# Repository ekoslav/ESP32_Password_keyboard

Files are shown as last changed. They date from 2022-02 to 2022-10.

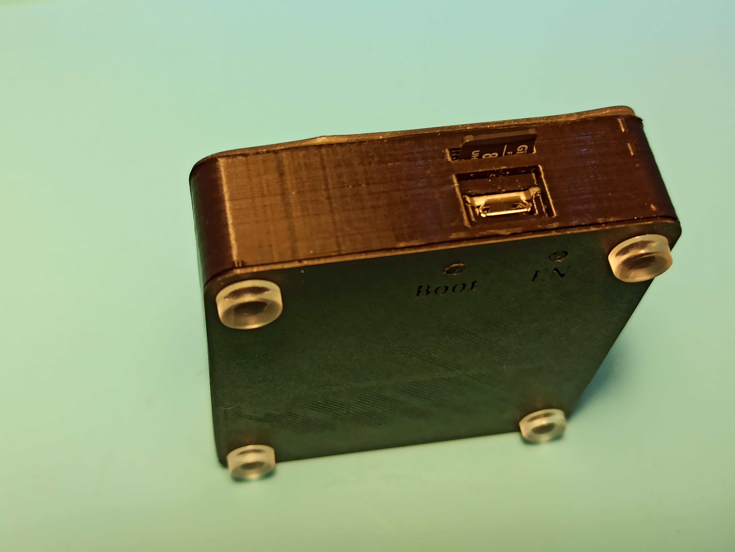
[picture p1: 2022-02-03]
Images/BACK_assembled.jpg

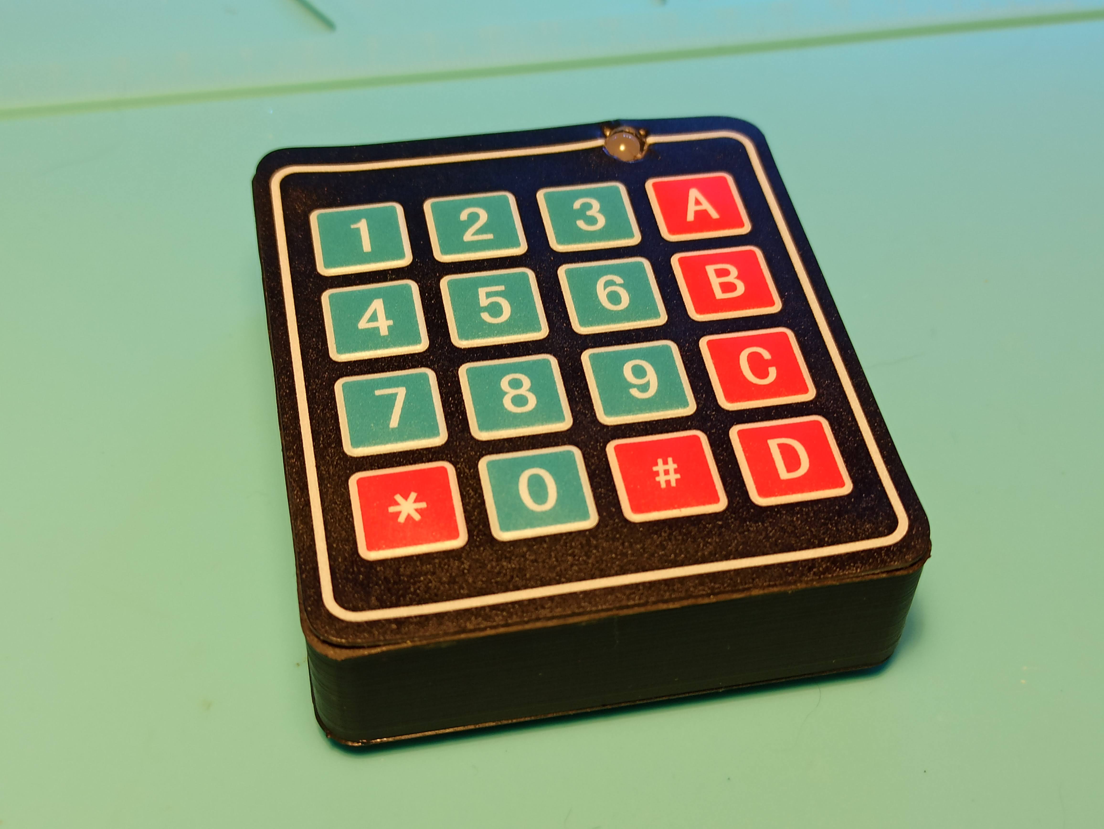
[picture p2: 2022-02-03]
Images/TOP_assembled.jpg

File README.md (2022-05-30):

# ESP32_Password_keyboard
Bluetooth password keyboard using the ESP32

Versions:

1.0 February 1st, 2022 - First public version

Description:

This project uses a ESP32, 4x4 matrix keyboard, an SD card reader, and a RGB LED.
The goal is to create a macro / password keyboard with 8 banks of 15 key mappings.

The star (*) key is used for shifting trought the key assignemnt banks.

Each bank has a corresponding file on the SD card.
The file should have 15 lines with macro sequences, and at least one blank line at the end.
The first line corresponds to the key "1", then 2 trough D, and the last is sequence for the key "#".

------------------------------------------------------------------------------------------------------
Examples for macro sequences:

1) just a plain text:

somekeycombination

2) text with tab key at the end:

username\t

3) text with enter key at the end:

password\n

or

password\r\n

4) text that has slash character ( exam\ple )

exam\\\ple

------------------------------------------------------------------------------------------------------

Here is the list of available special characters:

\n - adds ASCII char 10 - line feed

\r - adds ASCII char 13 - carriage return

\t - adds ASCII char 9 - horizontal tab

\e - adds ASCII char 27 - escape

\b - adds ASCII char 8 - backspace

\d - adds ASCII char 127 - delete

------------------------------------------------------------------------------------------------------
You can download 3D files for case here:
https://www.tinkercad.com/embed/aQZSsm0lfPb

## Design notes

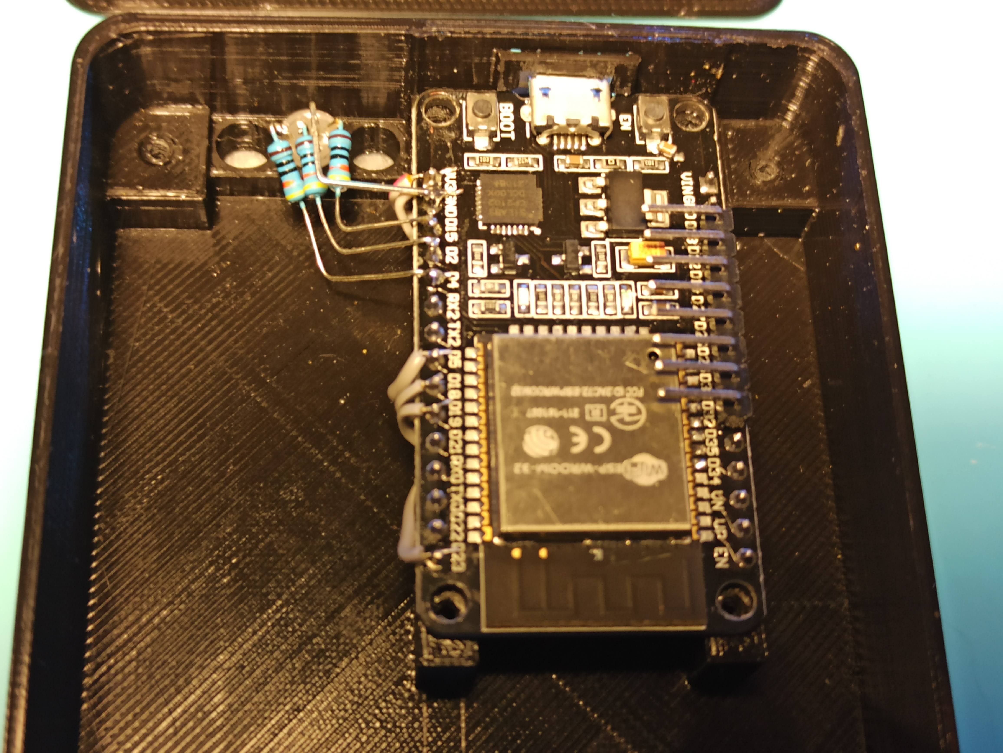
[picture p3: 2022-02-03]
Images/Inside_kbd_unplugged.jpg

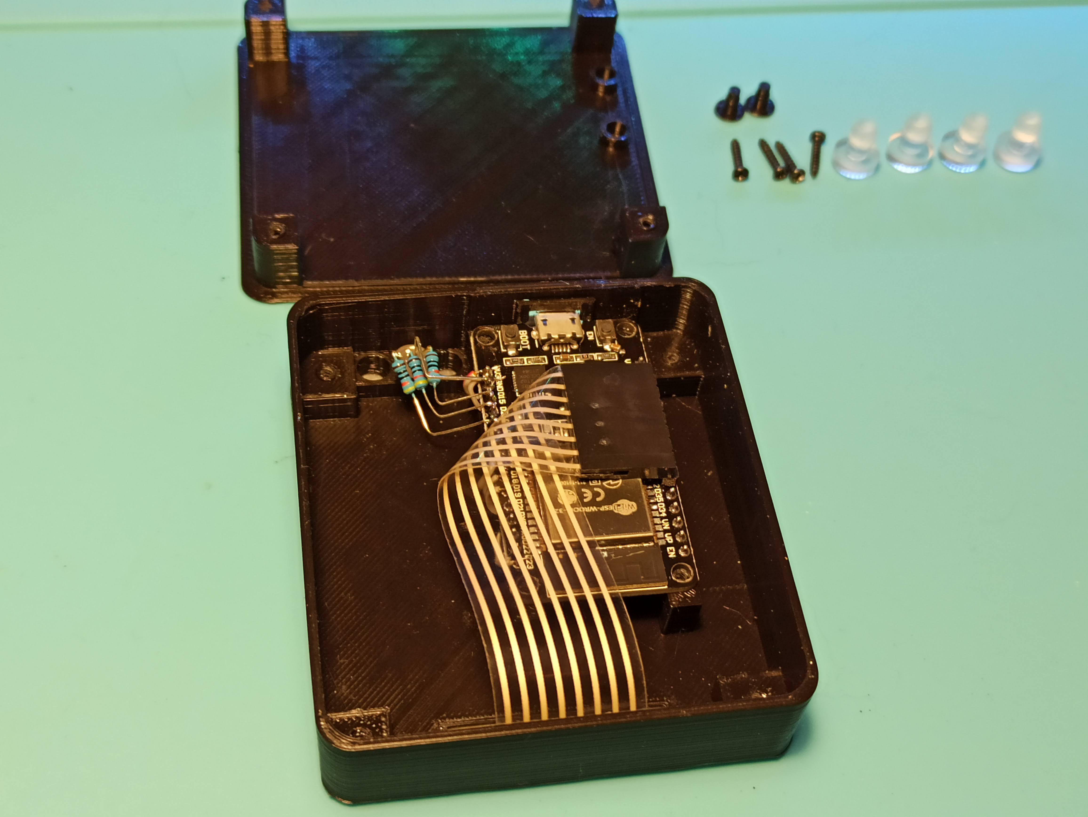
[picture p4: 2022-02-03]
Images/Inside_01.jpg

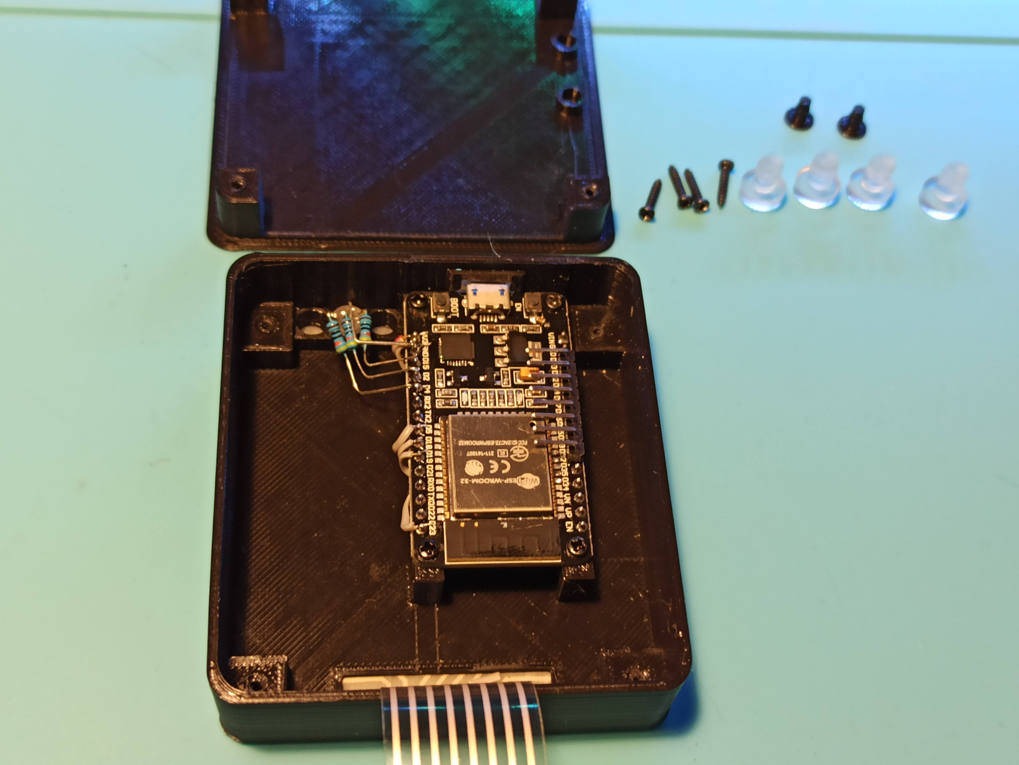
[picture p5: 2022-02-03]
Images/Inside_kbd_unplugged2.jpg

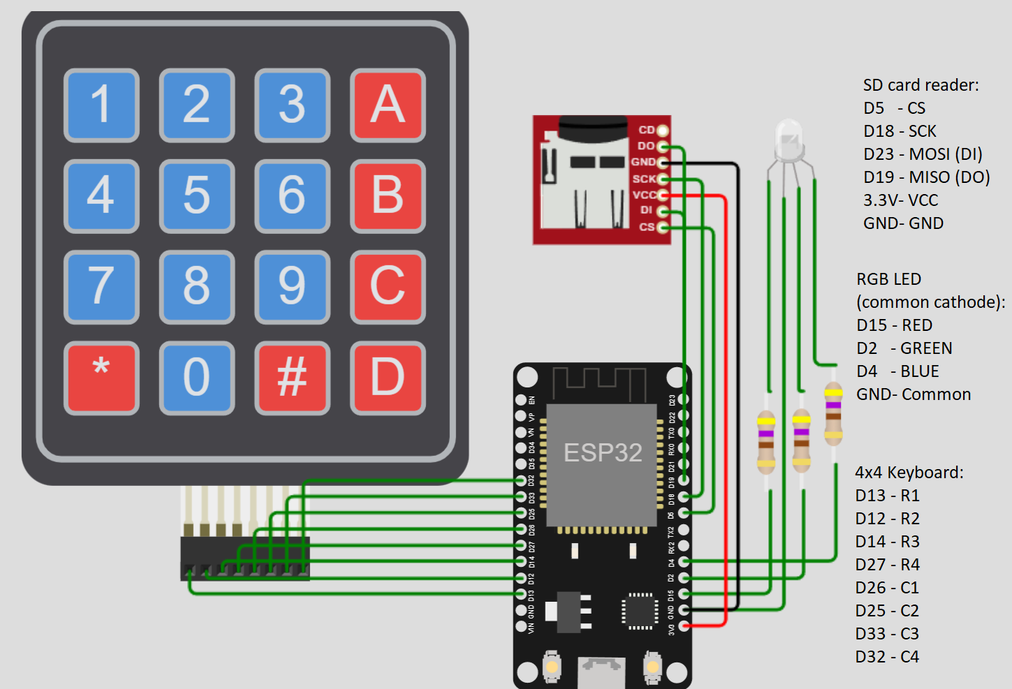
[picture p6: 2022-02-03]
Images/Connections.png

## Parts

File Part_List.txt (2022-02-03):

Part list:

1 x ESP32 devkit 1 (30 pin or 36 pin)
1 x 4x4 Membrane switch keypad
1 x SD card reader (Micro SD Storage Expansion Board)
1 x 5mm common cathode RGB LED  or  3 x 5mm LED ( red, green, blue )
3 x 470 ohm resistor

optional:

3D printed case top (https://www.tinkercad.com/things/aQZSsm0lfPb)
3D printed case bottom (https://www.tinkercad.com/things/aQZSsm0lfPb)
3D printed case buttons (https://www.tinkercad.com/things/aQZSsm0lfPb)
8 x M2.5 phillips self tapping screw, 8mm length
4 5mm Rubber Stem Bumpers Screws

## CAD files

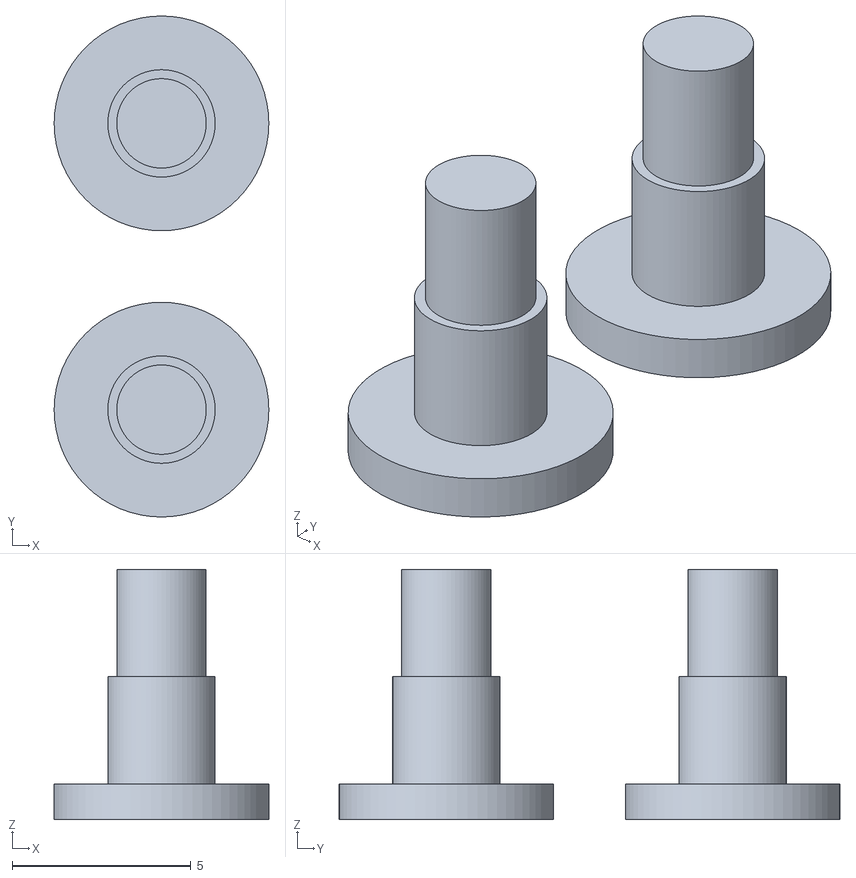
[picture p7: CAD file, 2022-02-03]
Case/MacroKeyboard_Buttons_exposed.stl
6.00 x 14.0 x 7.00

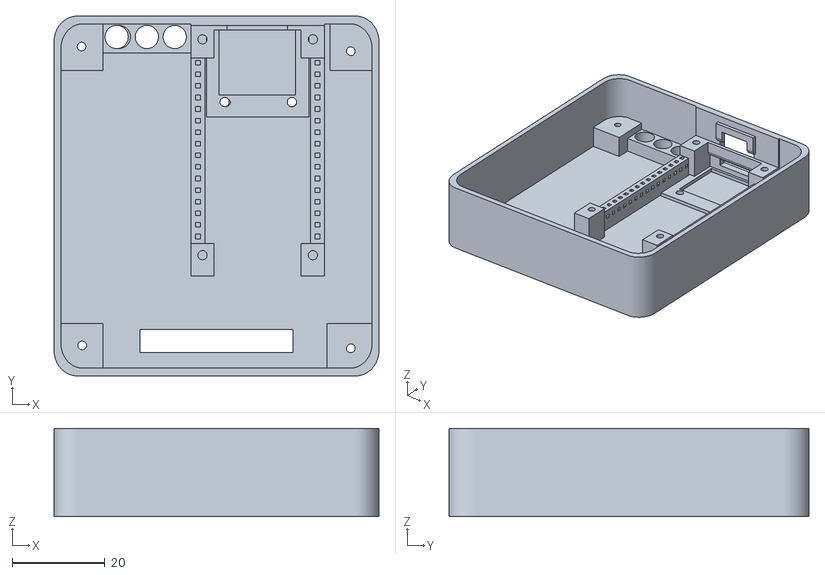
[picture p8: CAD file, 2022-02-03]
Case/MacroKeyboard_Top_30pin.stl
70.0 x 77.5 x 19.0

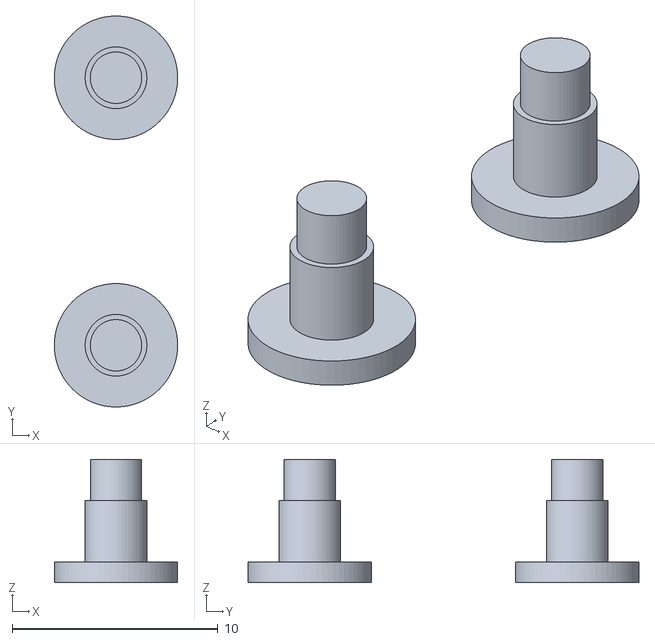
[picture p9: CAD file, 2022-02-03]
Case/MacroKeyboard_Buttons_flat.stl
6.00 x 19.0 x 6.00

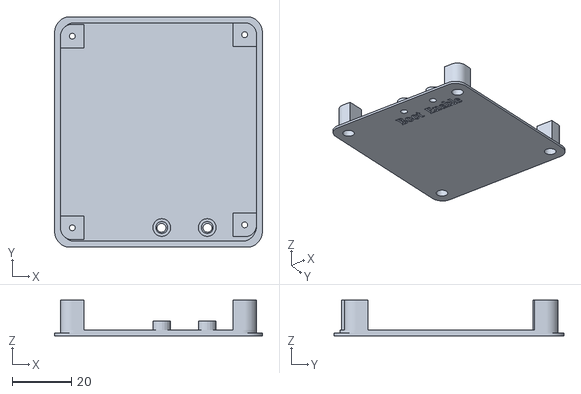
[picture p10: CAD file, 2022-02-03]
Case/MacroKeyboard_Bottom.stl
70.0 x 77.5 x 12.0

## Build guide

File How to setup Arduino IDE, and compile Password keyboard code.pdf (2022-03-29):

## How to setup Arduino IDE environment for ESP32

IDE and driver setup

1) Download and install the latest Arduino IDE: https://www.arduino.cc/en/software
2) Install with all options/drivers:

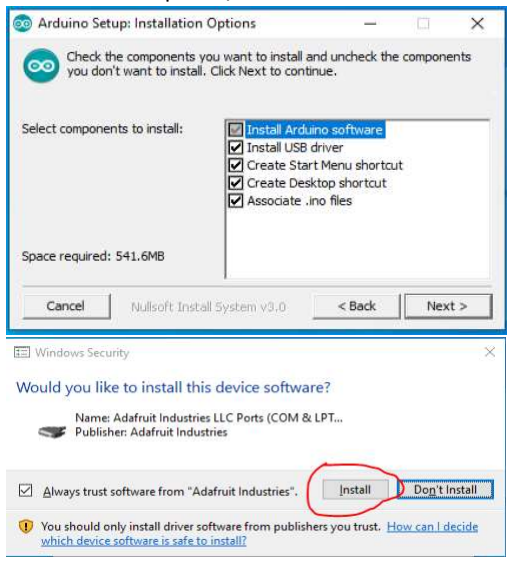
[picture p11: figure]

3) Install CP210X driver : https://www.silabs.com/developers/usb-to-uart-bridge-vcp-drivers

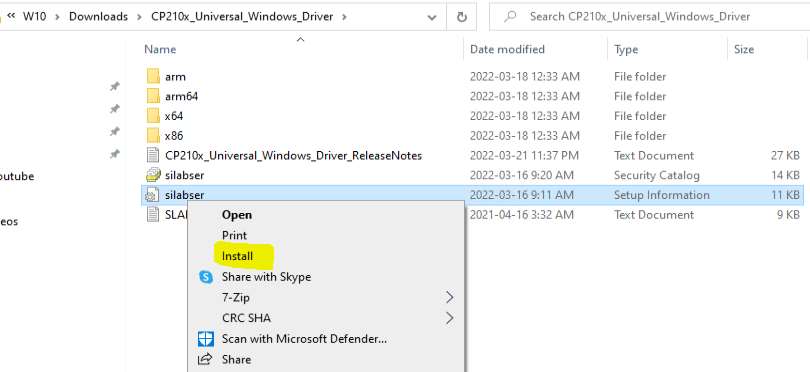
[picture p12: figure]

4) Plug in the device. You should see the COM port mapping in Device manager:

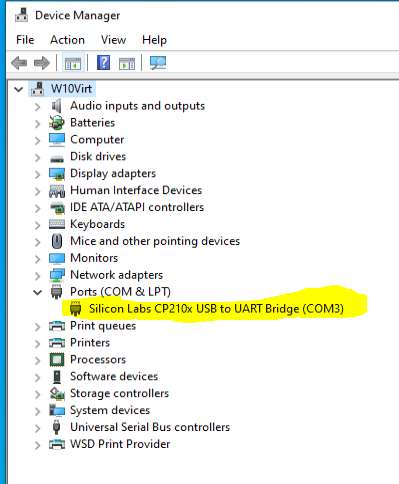
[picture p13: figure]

5) Launch Arduino IDE. Click on “File – Preferences”. Enter https://dl.espressif.com/dl/package_esp32_index.json into the “Additional Board Manager URLs” field:

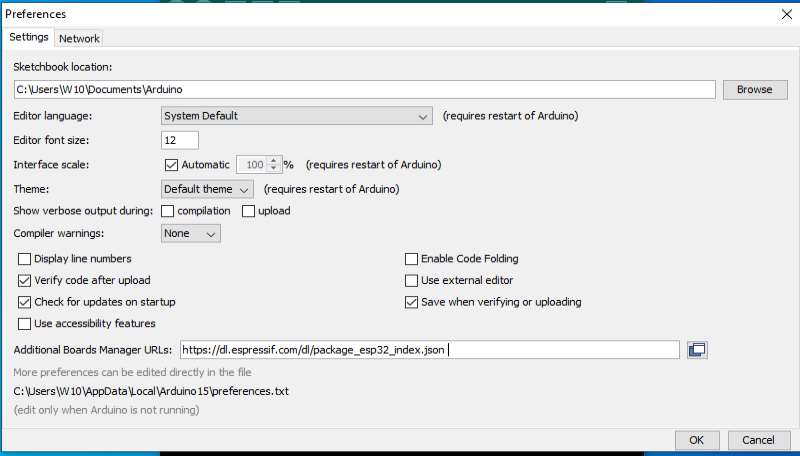
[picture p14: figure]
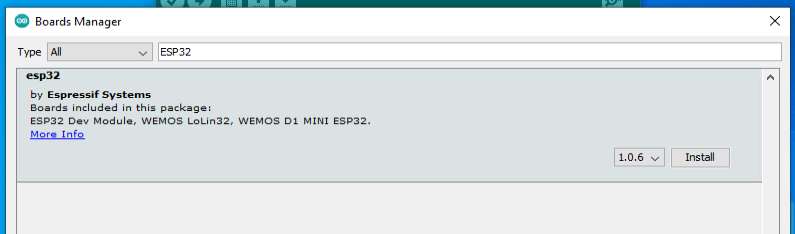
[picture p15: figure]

6) Install the ESP32 package in the “Tools – Board – Boards” manager:

7) Select the board “DOIT ESP32 DEVKIT 1”

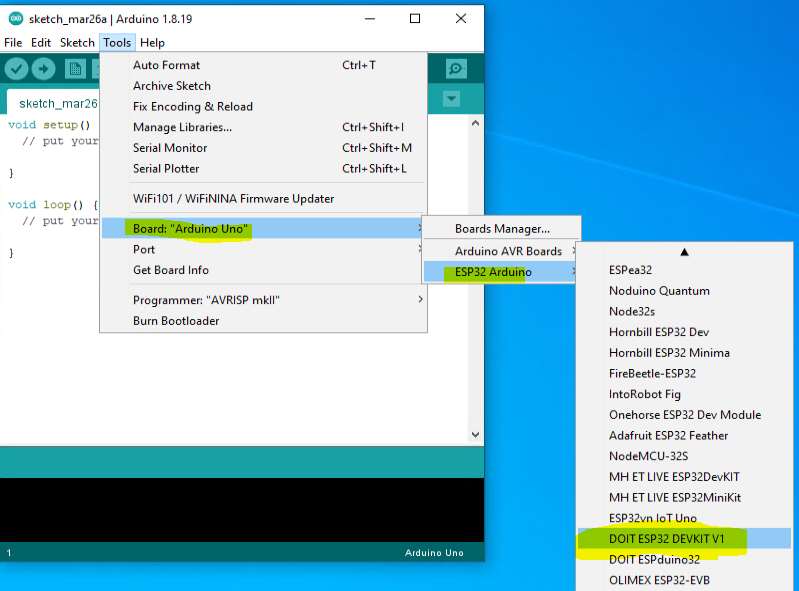
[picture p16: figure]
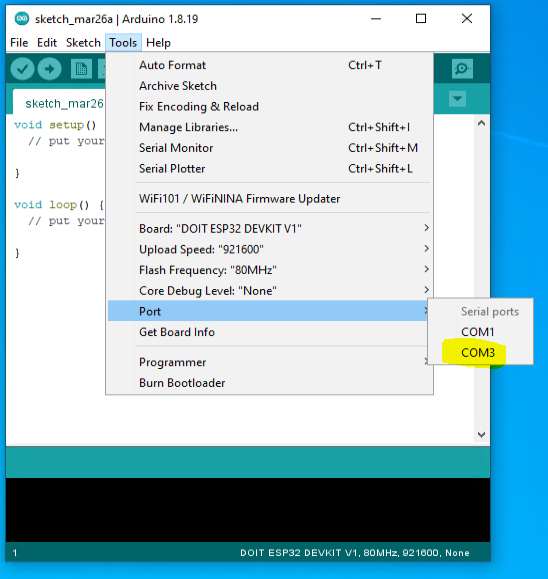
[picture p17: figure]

8) Select COM port for the board (see step 4):

9) Open “Serial monitor”.

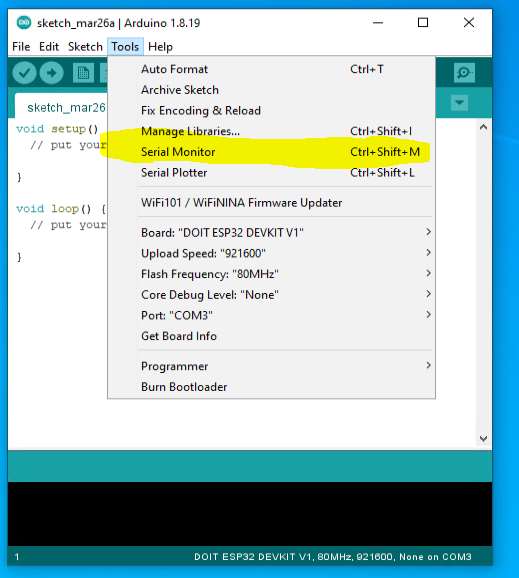
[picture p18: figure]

10) Adjust the baud rate to 115200:

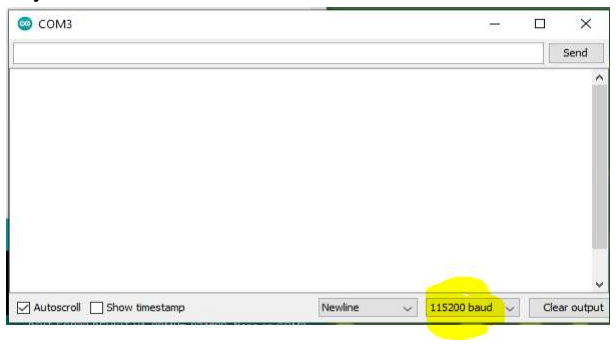
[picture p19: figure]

11) If you press the “Enable” button on the board / device, you should see messages like this:

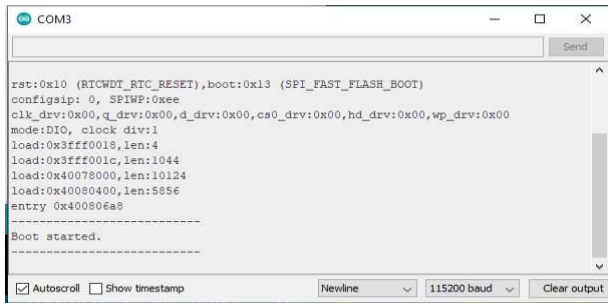
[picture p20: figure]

The system is now ready.

### Adding libraries

1) Click on “Tools – Manage Libraries”.
2) Type “Keypad” in the search box. Scroll down until you find this one:

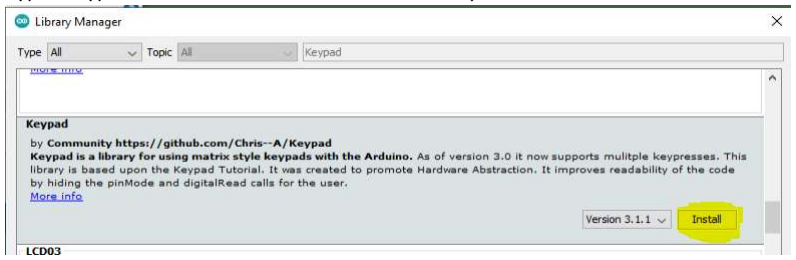
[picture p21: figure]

This library manages matrix keypads.
3) Next is a library that enables ESP32 board to act as a BT keyboard. It is a ZIP library. To install it, fist download the zip file from the repository: https://github.com/T-vK/ESP32-BLE-Keyboard/releases

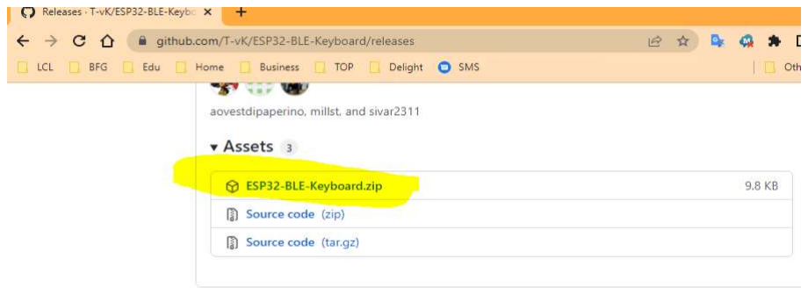
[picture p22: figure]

Download the file.
In the Arduino IDE go to "Sketch" -> "Include Library" -> "Add .ZIP Library..." and select the file you just downloaded.

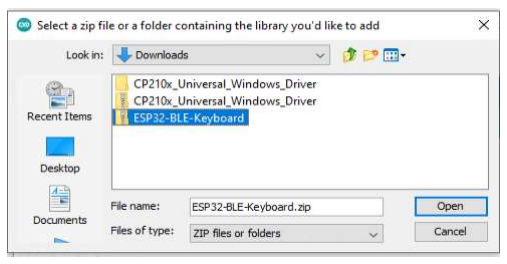
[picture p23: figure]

The IDE window will show success message:

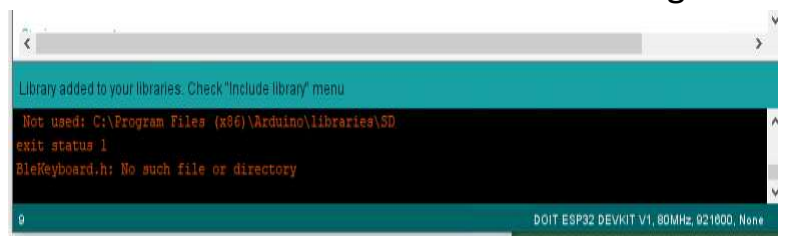
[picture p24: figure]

The libraries are now ready.

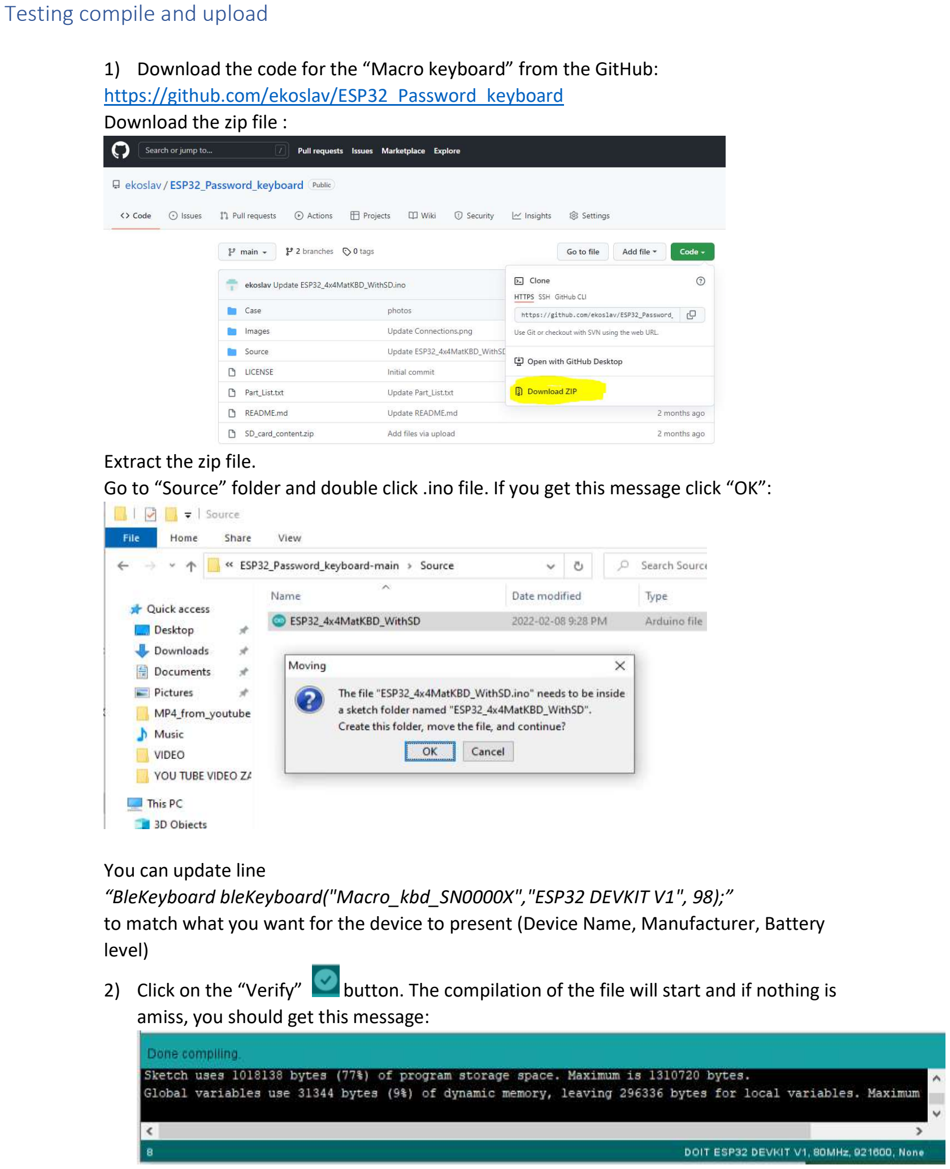
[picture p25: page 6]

### Testing compile and upload

1) Download the code for the “Macro keyboard” from the GitHub: https://github.com/ekoslav/ESP32_Password_keyboard
Download the zip file :

Extract the zip file.
Go to “Source” folder and double click .ino file. If you get this message click “OK”:

You can update line
“BleKeyboard bleKeyboard("Macro_kbd_SN0000X","ESP32 DEVKIT V1", 98);”
to match what you want for the device to present (Device Name, Manufacturer, Battery level)
2) Click on the “Verify” button. The compilation of the file will start and if nothing is amiss, you should get this message:

3) To flash the device with this code, open “Tools – Serial Monitor”.
On the board / device, press and hold “Enable” button, press and hold “Boot” button, release “Enable” button, and release “Boot” button.
You should see this message in the Serial Monitor:

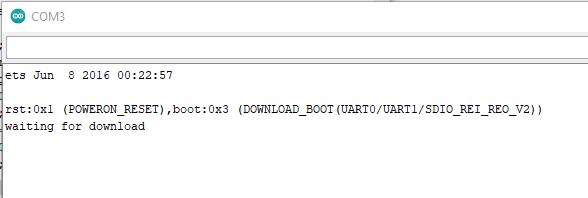
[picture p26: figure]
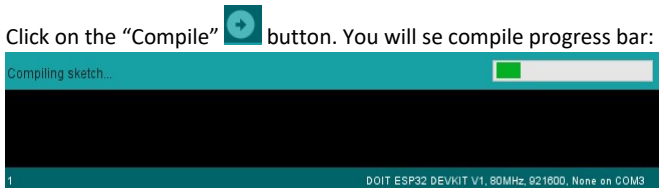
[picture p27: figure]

Click on the “Compile” button. You will se compile progress bar:

When completed you will see upload progress:

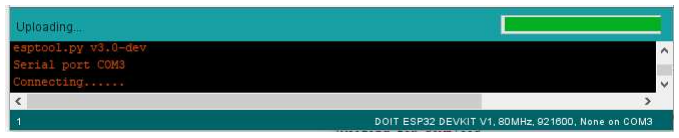
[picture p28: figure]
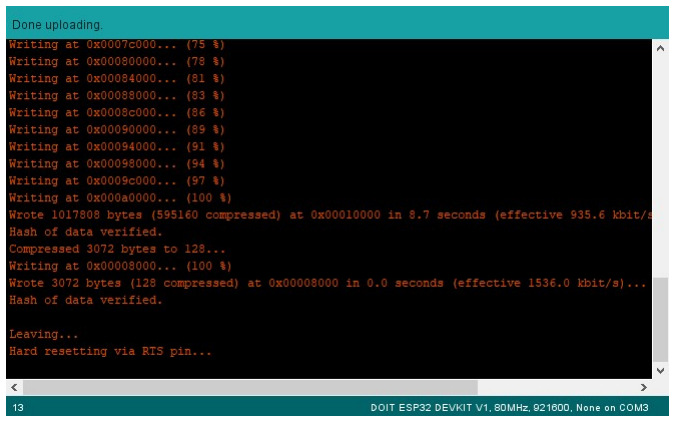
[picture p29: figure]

4) Once the process is completed, you can press the “Enable” button, and monitor the messages in the Serial monitor:

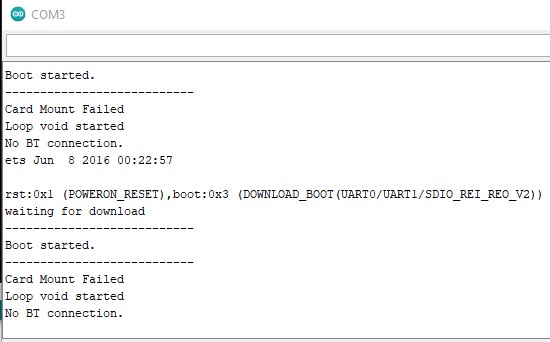
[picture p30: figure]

5) If you press “Enable” button, and see no messages in the Serial Monitor, close the Serial monitor window, and open it again.
6) If you get this error during the upload procedure, repeat the

“ press and hold “Enable” button, press and hold “Boot” button, release “Enable” button, and release “Boot” button”

when the “Connecting…” message shows up, but before it time outs.

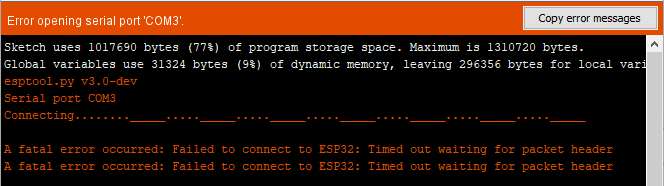
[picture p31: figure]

7) If you get error like this, simply repeat step 3. If you repeatedly get this error, and the Device manager shows proper COM port, you may need to reboot your computer.

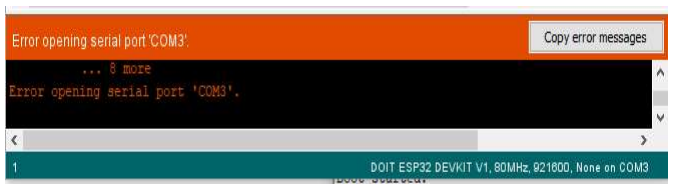
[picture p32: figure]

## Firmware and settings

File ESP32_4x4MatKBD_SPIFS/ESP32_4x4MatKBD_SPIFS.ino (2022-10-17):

String version ="Version 1.1 June 26,2022";
#include <FS.h>
#include <SD.h>
#include <SPI.h>
#include <SPIFFS.h>     // Filesystem support header
#include <ArduinoJson.h> // Using ArduinoJson to read and write config files
#include <WiFi.h> // Wifi support
#include <AsyncTCP.h>          //Async Webserver support header
#include <ESPAsyncWebServer.h> //Async Webserver support header
#include <ESPmDNS.h> // DNS functionality

#include <Keypad.h>
#include <BleKeyboard.h>
BleKeyboard bleKeyboard("Macro_kbd_MAC","ESP32 DEVKIT V1", 98);

String parameter;
byte line;
byte special;
String theArray[15];
String configArray[15];
int page=0;
int blinker=0;
int btlink=0;
int nobtlink=0;
int loopind=0;
int blocks=7; // Number of banks
int acounter=0;
int bcounter=0;
int ccounter=0;
int dcounter=0;
int typerate = 20;
int pagerate[] = {20, 200, 20, 200, 20, 200, 20, 200}; //typing rates for pages - even pages type slow

AsyncWebServer webserver(80);


#define FILESYSTEM SPIFFS
#define LED_RED   15
#define LED_GREEN   2
#define LED_BLUE   4


// ---- SETUP 4x4 matrix keyboard ---------------------
  const byte rows = 4; //four rows
  const byte cols = 4; //four columns
  char keys[rows][cols] = {
    {'A','3','2','1'},
    {'B','6','5','4'},
    {'C','9','8','7'},
    {'D','#','0','*'}
  };

  // keyboard DEVKIT V1 pins from left to right: 
  //  X1 X2 X3 X4 Y1 Y2 Y3 Y4 - right side
  //  13 12 14 27 26 25 33 32
  byte pin_rows[rows] = {13, 12, 14, 27};    // X1 X2 X3 X4 connect to the row pins
  byte pin_column[cols] = {32, 33, 25, 26}; // Y1 Y2 Y3 Y4 connect to the column pins 

  Keypad keypad = Keypad( makeKeymap(keys), pin_rows, pin_column, rows, cols  );
  //end keypad
  int shift = 0;
  int pshift = 0;
// ---- END SETUP 4x4 matrix keyboard ---------------------

void LEDblink(int repeats, int tdelay,int tdelay2, int ledcolor){
    for (int cycle = 0; cycle < repeats; cycle++){
        digitalWrite(ledcolor, HIGH);
        delay(tdelay);
        digitalWrite(ledcolor, LOW);
        delay(tdelay2);
      }
  }


// populates the deviceName char with the device Prefix plus a "unique" 4 char code
// thanks to webmonkey (https://github.com/webmonkey)
void getDeviceName(char* deviceName, char* devicePrefix) {
    uint64_t chipid = ESP.getEfuseMac();
    uint16_t shortid = chipid >> 32;
    char sprintfString[20] = "";
    strcat(sprintfString, devicePrefix);
    strcat(sprintfString, "_%04X");
    sprintf(deviceName, sprintfString, shortid);
}

void SetLED(String red, String green, String blue){
int lred;
int lgreen;
int lblue;
if (red=="1") {lred=HIGH;} else {lred=LOW;}
if (green=="1") {lgreen=HIGH;} else {lgreen=LOW;}
if (blue=="1") {lblue=HIGH;} else {lblue=LOW;}
digitalWrite(LED_RED, lred);
digitalWrite(LED_GREEN, lgreen);
digitalWrite(LED_BLUE, lblue);
}

void TestPrintln(){
  Serial.println("Test success");
  }

void CopyToPage(int page){
 Serial.print("Moving all keys to page #");
 Serial.print(page);
 Serial.println("(memory only, not saved");
  
  switch (page){
       case 0:
      SetLED("0","0","0");
      break;
      case 1:
      SetLED("0","1","0");
      break;
      case 2:
      SetLED("1","0","0");
      break;
      case 3:
      SetLED("0","0","1");
      break;
      case 4:
      SetLED("1","0","1");
      break;
      case 5:
      SetLED("0","1","1");
      break;
      case 6:
      SetLED("1","1","0");
      break;
      case 7:
      SetLED("1","1","1");
      break;
      
      }
  }

void SetPage(int page){
 Serial.print("Setting page #");
 Serial.println(page);
 String spshift = "/keys/keys" + String(page);
 String filename = String(spshift) + ".txt" ;
 const char* shfilename =  filename.c_str();
 readFile(shfilename);
 typerate = pagerate[page];
 Serial.print("[INFO]: typing speed is ");
 Serial.print(typerate);
 Serial.println(" ms");
  switch (page){
       case 0:
      SetLED("0","0","0");
      break;
      case 1:
      SetLED("0","1","0");
      break;
      case 2:
      SetLED("1","0","0");
      break;
      case 3:
      SetLED("0","0","1");
      break;
      case 4:
      SetLED("1","0","1");
      break;
      case 5:
      SetLED("0","1","1");
      break;
      case 6:
      SetLED("1","1","0");
      break;
      case 7:
      SetLED("1","1","1");
      break;
      
      }
  }

String getValue(String data, char separator, int index)
{
    int found = 0;
    int strIndex[] = { 0, -1 };
    int maxIndex = data.length() - 1;

    for (int i = 0; i <= maxIndex && found <= index; i++) {
        if (data.charAt(i) == separator || i == maxIndex) {
            found++;
            strIndex[0] = strIndex[1] + 1;
            strIndex[1] = (i == maxIndex) ? i+1 : i;
        }
    }
    return found > index ? data.substring(strIndex[0], strIndex[1]) : "";
}

void SetArrItem(char arkey, String arvalue)
{
    arvalue.trim();
    Serial.print("[INFO]: recv key name:");
    Serial.println(arkey);
    Serial.printf("[INFO]: recv key value: %s\n", arvalue);
    if      (arkey=='1') {theArray[0]=arvalue; }
    else if (arkey=='2') {theArray[1]=arvalue; }
    else if (arkey=='3') {theArray[2]=arvalue; }
    else if (arkey=='4') {theArray[3]=arvalue; }
    else if (arkey=='5') {theArray[4]=arvalue; }
    else if (arkey=='6') {theArray[5]=arvalue; }
    else if (arkey=='7') {theArray[6]=arvalue; }
    else if (arkey=='8') {theArray[7]=arvalue; }
    else if (arkey=='9') {theArray[8]=arvalue; }
    else if (arkey=='0') {theArray[9]=arvalue; }
    else if (arkey=='A') {theArray[10]=arvalue;}
    else if (arkey=='B') {theArray[11]=arvalue;}
    else if (arkey=='C') {theArray[12]=arvalue;}
    else if (arkey=='D') {theArray[13]=arvalue;}
    else if (arkey=='#') {theArray[14]=arvalue;}
    else {Serial.printf("Invalid key name");}    
}

void listAllFiles(){
 
  File root = SPIFFS.open("/");
 
  File file = root.openNextFile();
 
  while(file){
       Serial.println(file.name());
      file = root.openNextFile();
      } 
  }

void loadConfig (){
  Serial.printf("Reading file: /config/config.txt");
  line=0;
  File file = SPIFFS.open("/config/config.txt");
  memset(configArray, 0, sizeof(configArray));
  if(!file){
    Serial.println("Failed to open file for reading");
    return;
  }
  while(file.available()){
    char c = file.read();
    if (line<15){ // read only first 15 lines from the file
                if (isPrintable(c))  //if not end of the line  
                  {parameter.concat(c);
                   }
                else if (c == '\n')  // this is end of the line 
                  { configArray[line] = parameter; // add collected chars to element in array corresponding to the keyboard button 
                    Serial.print(".");
                    parameter = "";
                    line++;
                    }
              }
  
  }
 Serial.println();
 Serial.println("Done.");
 Serial.println();
 file.close();
}

void readFile(const char * path){
  Serial.printf("Reading file: %s\n", path);
  line=0;
  File file = SPIFFS.open(path);
  memset(theArray, 0, sizeof(theArray));
  if(!file){
    Serial.println("Failed to open file for reading");
    return;
  }
  while(file.available()){
    char c = file.read();

  if (line<15){ // read only first 15 lines from the file
    if (isPrintable(c))  //if not end of the line
    {
       parameter.concat(c);
      
      }
    else if (c == '\n')  // this is end of the line
        {
        theArray[line] = parameter; // add collected chars to element in array corresponding to the keyboard button 
        Serial.print(".");
        parameter = "";
        line++;
        }

    }
  
  }
 Serial.println();
 Serial.println("Done.");
 Serial.println();
 file.close();
}

void writeConfig(){
  //-------------- begin write file ----------------
 String filename = "/config/config.txt"; 
 Serial.println(filename);
 File file = SPIFFS.open(filename, "w");
  if (!file) {
    Serial.println("Error opening file for writing");
    return;
  }
  Serial.println("[INFO]: file seem to open for writing. ");
  //loop
  int bytesWritten = 0;
  int bytesLWritten = 0;
  String fileline = "";
  for (int i = 0; i < 15; i++) {
        // write line from array
        fileline = configArray[i];
        Serial.print("[INFO]: writing line ");
        Serial.print(i);
        Serial.print(" : ");
        Serial.println(fileline);
        
        bytesLWritten = file.println(fileline);
        bytesWritten = bytesWritten + bytesLWritten;
        Serial.print("[INFO]: bytes written: ");
        Serial.println(bytesLWritten);
        # bytesLWritten = 0; 
        }
  Serial.print("[INFO]: Total bytes written: ");
  Serial.println(bytesWritten);
  if (bytesWritten == 0) {
    Serial.println("Config File write failed");
    //return;
  }
  file.close();
  File file2 = SPIFFS.open(filename, "r");
  if (!file2) {
    Serial.println("Failed to open config file for reading");
    return;
  }
  Serial.println("[INFO]: config file seem to open for reading. ");
  Serial.println("Config File Content:");
 
  while (file2.available()) {
 
    Serial.write(file2.read());
  }
 
  file2.close();
  
  //---------------- end write file ----------------
  }
  
void readFile(String filename){
  Serial.print("[INFO] Opening file ");
  Serial.print(filename);
  Serial.println(" for reading");
  File file = SPIFFS.open(filename, "r");
  if (!file) {
    Serial.println("Failed to open file for reading");
    return;
  }
  Serial.println("[INFO]: file seem to open for reading. ");
  Serial.println("File Content:");
  while (file.available()) {
    Serial.write(file.read());
    }
  file.close();
  Serial.println("End of file");
  }

void writePage(int page){
  //-------------- begin write file ----------------
 Serial.print("[INFO]: Page number is ");
 Serial.println(page);
  // write content of currently loaded page to file
 String filenamep1 = "/keys/keys" + String(page);
 String filename = String(filenamep1) + ".txt"; 
  Serial.print("[INFO]: file name is ");
  Serial.println(filename);
  File file = SPIFFS.open(filename, "w");
  if (!file) {
    Serial.println("Error opening file for writing");
    return;
  }
  Serial.println("[INFO]: file seem to open for writing. ");
  //loop
  int bytesWritten = 0;
  int bytesLWritten = 0;
  String fileline = "";
  for (int i = 0; i < 15; i++) {
        // write line from array
        fileline = theArray[i];
        Serial.print("[INFO]: writing line ");
        Serial.print(i);
        Serial.print(" : ");
        Serial.println(fileline);
        
        bytesLWritten = file.println(fileline);
        bytesWritten = bytesWritten + bytesLWritten;
        Serial.print("[INFO]: bytes written: ");
        Serial.println(bytesLWritten);
        bytesLWritten = 0; 
        }
  Serial.print("[INFO]: Total bytes written: ");
  Serial.println(bytesWritten);
  if (bytesWritten == 0) {
    Serial.println("File write failed");
    //return;
  }
  Serial.println("about to file.close();");
  file.close();
 
  Serial.println("[INFO] Opening file for reading");
  File file2 = SPIFFS.open(filename, "r");
 
  if (!file2) {
    Serial.println("Failed to open file for reading");
    return;
  }
  Serial.println("[INFO]: file seem to open for reading. ");
  Serial.println("File Content:");
 
  while (file2.available()) {
 
    Serial.write(file2.read());
  }
 
  file2.close();
  
  //---------------- end write file ----------------
  }

void SendSequence(String sequence){
  // send sequence to bluetooth one char at the time
  Serial.print("[INFO]: typing speed is ");
  Serial.print(typerate);
  Serial.println(" ms");
  Serial.println(sequence);
  int len = sequence.length();
  Serial.println(len);
  //Serial.println("---------------");
  int special=0;
  for (int i=0;i<=len;i++) {
    // analysis of the string
    //is it special char?
      if (special == 1) {
            Serial.print("Special char selection for ");
            Serial.print("|");
            Serial.print(sequence.charAt(i));
            Serial.println("| ");
            Serial.println(i);
            if (sequence.charAt(i) == 'r') {special=0;bleKeyboard.write(KEY_RETURN);Serial.println("[KEY_RETURN]");}    //add CR
            else if (sequence.charAt(i) == 's') {special=0;bleKeyboard.write(32);Serial.println("[SPACE]");}    //add space
            else if (sequence.charAt(i) == 'c') {special=0;bleKeyboard.write(':');Serial.println(":");}    //add colon
            else if (sequence.charAt(i) == 't') {special=0;bleKeyboard.write(KEY_TAB);Serial.println("[KEY_TAB]");}       //add horizontal tab
            else if (sequence.charAt(i) == '\\') {special=1;bleKeyboard.print('\\');Serial.println("[\\]");}       //Dual slash situation
            else {
                //if not expected special char,turn off special, and add it to the string
                special=0;
                bleKeyboard.print("\\");
                bleKeyboard.print(sequence.charAt(i));
                }                        
          }        
      else { //regular char

        if(sequence.charAt(i) == '\\') {
          special=1;
          Serial.print(i);
          Serial.print(":");
          Serial.println("<Escape char>");
          } //escape char, turn on special for next char
        else {
  
          Serial.print(i);
          Serial.print(":");
          Serial.println(sequence.charAt(i));
          bleKeyboard.print(sequence.charAt(i));
          //} 
        }
      // to avoid repeating characters
      bleKeyboard.releaseAll();
      delay(typerate);
      }

    
    }
  Serial.println("---------------");
  }

void printHelp() {
      Serial.println(version);
      Serial.println("[INFO]: Available commands: ");
      Serial.println("All commands require one space unless they have attribute following command. ");
      Serial.println();
      Serial.println("reboot");
      Serial.println("ls");
      Serial.println("rm");
      Serial.println("cat");
      Serial.println("help");
      Serial.println("setspeed XXX - sets typing speed at XXXms / char");
      Serial.println("fast - sets typing speed at 20ms / char");
      Serial.println("slow - sets typing speed at 200ms / char");
      Serial.println("extraslow - sets typing speed at 400ms / char");
      Serial.println("setpage");
      Serial.println("listpage");
      Serial.println("getpage");
      Serial.println("nextpage");
      Serial.println("copytopage x - copies all keys to page x, without saving to file");
      Serial.println("writepage");
      Serial.println("setkey KEY:Value");
      Serial.println("[EXAMPLE] setkey B:78456a$06\\r ");
      Serial.println("The key B is assigned sequence 78456a$06 with RETURN key at the end. ");
      Serial.println("Options are \\r for RETURN key, \\t for TAB key, \\s for space, \\c for colon, \\\\ for \\. ");
      Serial.println();
      Serial.println("setled NUMBER[0-7]");
      Serial.println("numofpages NUMBER[0-7]");
      Serial.println();
  
  }
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
void loop()
{
  if(loopind==0){loopind=1;Serial.println("Loop void started");}
    
  //Check commands over serial  
  if (Serial.available())
  {
    String input = Serial.readStringUntil(10);
    String command = getValue(input, ' ', 0);
    String attribute = getValue(input, ' ', 1);
    Serial.print("[INFO]: Command: ");
    Serial.println(command);
    Serial.print("[INFO]: Attribute: ");
    Serial.println(attribute);
    
    if (command == "reboot"){
      ESP.restart();
    }
    else if (command == "setpage"){
      //String value = Serial.readString();
      int npage = attribute.toInt(); 
        Serial.print("[INFO]: Changed page to: ");
        Serial.println(npage);
        shift = npage;
        pshift = npage;
        SetPage(npage);
    }
    else if (command == "copytopage"){
      //String value = Serial.readString();
      int npage = attribute.toInt(); 
        Serial.print("[INFO]: Changed page to: ");
        Serial.println(npage);
        shift = npage;
        pshift = npage;
        CopyToPage(npage);
    }
    else if (command == "listpage"){
        String k;
        for (int i=0;i<15;i++) {
            k=String(i+1);
            if (i==9) {k="0";}
            if (i==10) {k="A";}
            if (i==11) {k="B";}
            if (i==12) {k="C";}
            if (i==13) {k="D";}
            if (i==14) {k="#";}
            Serial.print("setkey ");
            Serial.print(k);
            Serial.print(":");
            Serial.println(theArray[i]);
        }
    }
    
    else if (command == "getpage"){
        Serial.print("[INFO]: Current page: ");
        Serial.println(shift);
    }
    
    else if (command == "nextpage"){
            if (page==7){pshift=0;}
            else {pshift=pshift+1;} 
            SetPage(pshift); 
    }
    
    else if (command == "setkey")
    {
      String keyname = getValue(attribute, ':', 0);
      String keyvalue = getValue(attribute, ':', 1);
      char arrkey = keyname.charAt(0);
      Serial.print("[INFO]: sent_arrkey: ");
      Serial.println(arrkey);
      Serial.print("[INFO]: send_keyvalue: ");
      Serial.println(keyvalue);
      SetArrItem(arrkey,keyvalue);
      }

else if (command == "setled")
    {
      String red = getValue(attribute, ',', 0);
      String green = getValue(attribute, ',', 1);
      String blue = getValue(attribute, ',', 2);
      Serial.print("SetLED(");
      Serial.print(red);
      Serial.print(",");
      Serial.print(green);
      Serial.print(",");
      Serial.print(blue);
      Serial.println(");");
      SetLED(red,green,blue);
      }

else if (command == "numofpages")
    {
      Serial.print("Original total pages: ");
      Serial.println(blocks);
      int blocksp = attribute.toInt();
      blocks =  blocksp-1;
      configArray[0]=String(blocksp);
      Serial.print("[INFO]: Number of pages set to  ");
      Serial.println(blocksp);
      Serial.print("Total pages: ");
      Serial.println(blocksp);
      writeConfig();
      SetPage(0);
      
      }
else if (command == "writepage")
    {
      Serial.print("[INFO]: Writing current keys to keys page ");
      Serial.println(shift);
      writePage(shift);
      }

else if (command == "version")
    {
      Serial.println(version);
      }

else if (command == "writeconfig") {writeConfig();}
else if (command == "loadconfig")  {loadConfig();}
else if (command == "ls") {Serial.println("[INFO]: list of files on SPIFFS "); listAllFiles(); }
else if (command == "test") {TestPrintln();}
else if (command == "cat"){Serial.print("[INFO]: Content of the file ");Serial.println(attribute);readFile(attribute);}
else if (command == "setspeed")
    {
      typerate = attribute.toInt();    
      Serial.print("[INFO]: typing speed is ");
      Serial.print(typerate);
      Serial.println(" ms");  
      }
else if (command == "fast")
    {
      typerate = 20;    
      Serial.print("[INFO]: typing speed is ");
      Serial.print(typerate);
      Serial.println(" ms");  
      }
else if (command == "slow")
    {
      typerate = 200;
      Serial.print("[INFO]: typing speed is ");
      Serial.print(typerate);
      Serial.println(" ms");
      }          
else if (command == "rm")
    {
      
      attribute.trim();
      Serial.print("[INFO]: Deleting file ");
      Serial.print("|");
      Serial.print(attribute);
      Serial.println("|");
      Serial.println("\n\n---BEFORE REMOVING---");
      listAllFiles();
      SPIFFS.remove(attribute);
      Serial.println("\n\n---AFTER REMOVING---");
      listAllFiles();
      }
else if (command == "help")
    {
      printHelp();
      }
    
  }



  // BLE start
  if(bleKeyboard.isConnected()) {
    if(btlink==0){btlink=1;nobtlink=0;Serial.println("BT connected!");}
    delay(10);
    char result = keypad.getKey();
    if (result != NO_KEY){
      String ssequence="";
      Serial.print("Key pressed: ");
      Serial.println(result);
      if      (result=='1') {SendSequence(theArray[0]); }
      else if (result=='2') {SendSequence(theArray[1]); }
      else if (result=='3') {SendSequence(theArray[2]); }
      else if (result=='4') {SendSequence(theArray[3]); }
      else if (result=='5') {SendSequence(theArray[4]); }
      else if (result=='6') {SendSequence(theArray[5]); }
      else if (result=='7') {SendSequence(theArray[6]); }
      else if (result=='8') {SendSequence(theArray[7]); }
      else if (result=='9') {SendSequence(theArray[8]); }
      else if (result=='0') {SendSequence(theArray[9]); }
      else if (result=='A') {SendSequence(theArray[10]);acounter++;}
      else if (result=='B') {SendSequence(theArray[11]);bcounter++;}
      else if (result=='C') {SendSequence(theArray[12]);ccounter++;}
      else if (result=='D') {SendSequence(theArray[13]);dcounter++;}
      else if (result=='#') {SendSequence(theArray[14]);}
      else if (result=='*') {
            Serial.print("Total pages: ");
            Serial.println(blocks);
            if (shift==blocks){pshift=0;}
            else {pshift=pshift+1;} 
            SetPage(pshift);
            }
    Serial.print("Key A pressed times:");Serial.println(acounter);
    Serial.print("Key B pressed times:");Serial.println(bcounter);
    Serial.print("Key C pressed times:");Serial.println(ccounter);
    Serial.print("Key D pressed times:");Serial.println(dcounter);   
    shift = pshift;
    delay(20); //prevent double keystrokes
    }
  } //BLE connected end
    else {
    //ble not connected
    LEDblink(1,50,100,LED_BLUE);
    delay(500); // wait for .5 seconds
    if(nobtlink==0){nobtlink=1;btlink=0;Serial.println("No BT connection.");}
    
  }

}

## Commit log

2022-02-03 Update ESP32_4x4MatKBD - Blank.ino
2022-03-29 Create How to setup Arduino IDE, and compile Password keyboard code.pdf
2022-05-30 SPIFS v0.1 correction folder name
    [ESP32_4x4MatKBD_SPIFS.ino]
2022-06-26 Update ESP32_4x4MatKBD_SPIFS.ino
    Version 1.1
    added commands:
    All commands require one space unless they have attribute following command.
    reboot
    ls
    rm
    help
    fast - sets typing speed at 20ms / char
    slow - sets typing speed at 200ms / char
    extraslow - sets typing speed at 400ms / char
    setpage
    listpage
    getpage
    nextpage
    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
    [ESP32_4x4MatKBD_SPIFS.ino]
2022-07-08 Update ESP32_4x4MatKBD_SPIFS.ino
    Even pages set to slow by default
2022-07-15 Update ESP32_4x4MatKBD_SPIFS.ino
    Added more speed controls, file commands
2022-08-02 Update ESP32_4x4MatKBD_SPIFS.ino
    Updated to reflect unique BT name
